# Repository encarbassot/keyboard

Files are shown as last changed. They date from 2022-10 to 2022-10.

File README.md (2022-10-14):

# Arduino Keyboard

- [Keyboard customization](keyboards/README.md)
- [How Keyboard hardware basic](playground/inputMatrix/README.md)
- [How Keyboard hardware DECO-MUX](playground/deco-mux/README.md)
- [Keyboard code examples](playground/README.md)

# Keyboards I've build

## Keyboard 48
more about [here](keyboard48/README.md)
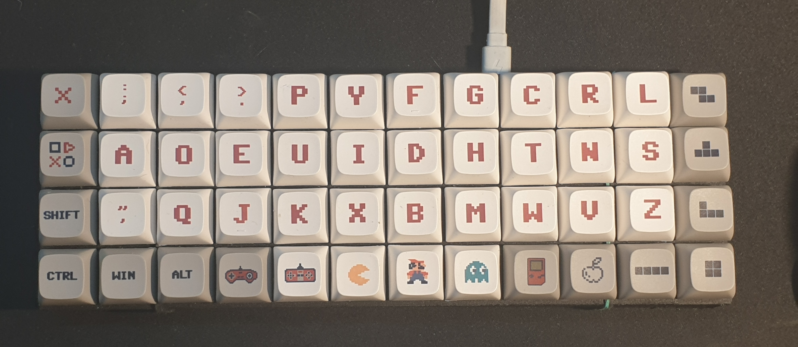
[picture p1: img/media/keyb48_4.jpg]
Keyboard 48


## Keyboard 64
more about [here](keyboard64/README.md)
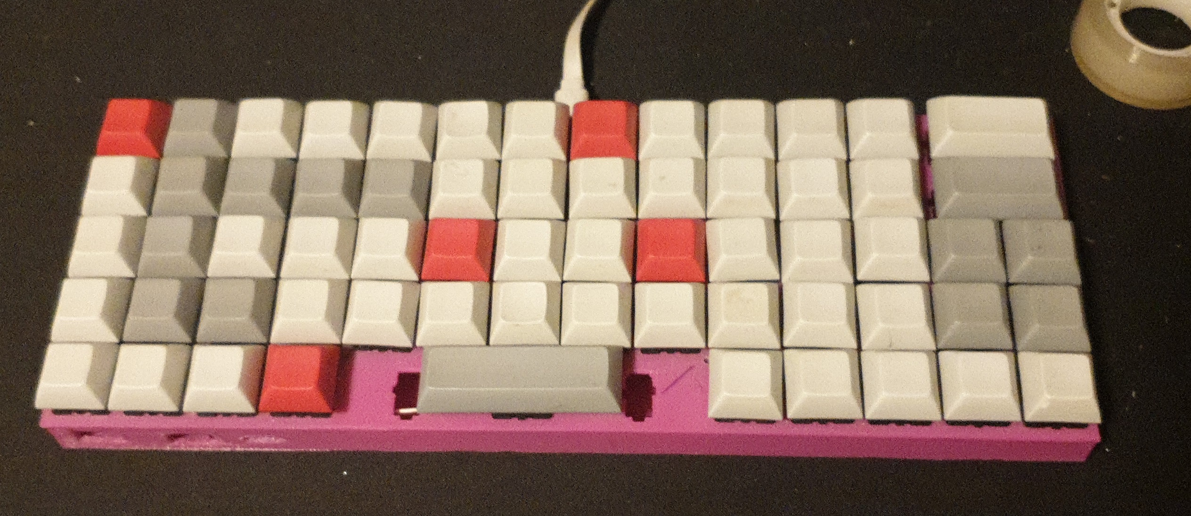
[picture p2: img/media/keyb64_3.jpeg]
Keyboard 64


All the documentation has been written by its own keyboard

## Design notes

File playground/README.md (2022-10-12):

# Playground
here are some codes that may help to understand de functionality of the keyboard
this wants to be a none over complicated way to understand the deep code of keyboard

## Learn more about DECODIFICATOR and MULTIPLEXOR
[DCO & MUX](deco-mux/README.md)

## Example codes
 - [deco-mux.ino](deco-mux/deco-mux/deco-mux.ino) explains how a **Multiplexer** and a **Decoder** works
 - [deco-mux-matrix.ino](deco-mux/deco-mux-matrix/deco-mux-matrix.ino) explains how to read a button matrix with a **Multiplexer** and a **Decoder**
 - [matrixInp.ino](inputMatrix/matrixInp/matrixInp.ino) Reads a button matrix without a multiplexer or decoder, raw input from row/column to Arduino input/output
 - [ascii.ino](ascii/ascii.ino) emulates a keyboard key press for each key that can exist and prints a table with the codes of ach key

 ## Interesting to include the next functionalities to the keyboard
 - [sd.ino](sd/sd.ino) reads a microSD and outputs the contents of a file
 - [oled.ino](oled/oled.ino) shows information via oled **SSD1306** (128×32) or (128x64) with [Adafruit library](https://github.com/adafruit/Adafruit_SSD1306)
 - [bluetooth.ino](bluetooth/bluetooth.ino) communication with phone to write from an app

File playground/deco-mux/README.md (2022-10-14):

# DECODER & MULTIPLEXOR

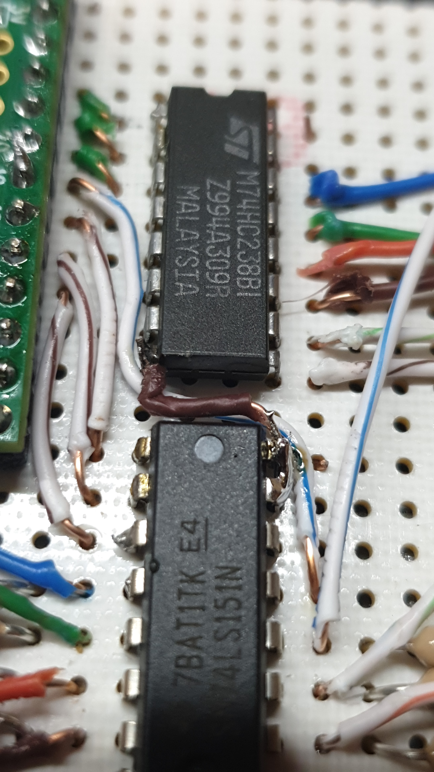
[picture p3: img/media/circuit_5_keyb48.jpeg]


### CODE EXAMPLES
  - [deco-mux.ino](deco-mux/deco-mux.ino) explains how a **Multiplexer** and a **Decoder** works
  - [deco-mux-matrix.ino](deco-mux-matrix/deco-mux-matrix.ino) explains how to read a button matrix with a **Multiplexer** and a **Decoder**
## Decoder
 - see on [wikipedia](https://wikipedia.org/wiki/Decodificador)  
 - [74HC238 datasheet](../../documentation/datasheet-DECO-M74HC238_STMicroelectronics.pdf)  

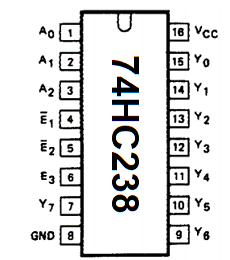
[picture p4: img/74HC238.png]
74HC238 pinout

 - **(A0,A1,A2)**-> microcontroller selector
 - **(Y0,Y1...Y6,Y7)**-> Decoder outputs
 - **(!E1,!E2,E3)** -> bring the option to connect 4 of them to create an **ULTRA-DECODER**
    - **!E1** and **!E2** set to ground (for normal operation)
    - **E3** set to 5V (for normal operation)
 - **VCC & GND** -> 🙃

A decoder has **n** inputs and **2<sup>n</sup>** outputs  
And what it does it's to trigger only the output that matches the input binary combination

for the **74HC238** that I'm using on the project, the output table is the next:

| A | B | C || Y0 | Y1 | Y2 | Y3 | Y4 | Y5 | Y6 | Y7 |
|---|---|---|-|----|----|----|----|----|----|----|----|
🔴|🔴|🔴| |🟢|🔴|🔴|🔴|🔴|🔴|🔴|🔴|
🔴|🔴|🟢| |🔴|🟢|🔴|🔴|🔴|🔴|🔴|🔴|
🔴|🟢|🔴| |🔴|🔴|🟢|🔴|🔴|🔴|🔴|🔴|
🔴|🟢|🟢| |🔴|🔴|🔴|🟢|🔴|🔴|🔴|🔴|
🟢|🔴|🔴| |🔴|🔴|🔴|🔴|🟢|🔴|🔴|🔴|
🟢|🔴|🟢| |🔴|🔴|🔴|🔴|🔴|🟢|🔴|🔴|
🟢|🟢|🔴| |🔴|🔴|🔴|🔴|🔴|🔴|🟢|🔴|
🟢|🟢|🟢| |🔴|🔴|🔴|🔴|🔴|🔴|🔴|🟢|

see it on action  
decpder gif

## Multiplexor
 A multiplexor its basically an input selector
 it has **n** channel selectors, **2<sup>n</sup>** inputs and 1 output  
 with the microcontroller, you can select any input by setting the channel selectors **HIGH** or **LOW**  
 then it will set its output to the value of the selected input

 - see on [wikipedia](wikipedia.org/wiki/Multiplexor)
 - [74LS151 datasheet](../../documentation/datasheet-MUX-74LS151.pdf)

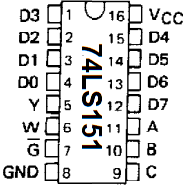
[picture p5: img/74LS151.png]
74LS151 pinout

 - **(A,B,C)**-> microcontroller channel selector
 - **(D0,D1..D6,D7)** -> Multipexor inputs
 - **(Y,W)** 
    - **Y** -> output
    - **W** -> negated output
 - **G** -> set to ground for formal operation

 | C|B|A|| Y | W |
|---|---|-|--|----|-|
🔴|🔴|🔴| |D0|!D0|
🔴|🔴|🟢| |D1|!D1|
🔴|🟢|🔴| |D2|!D2|
🔴|🟢|🟢| |D3|!D3|
🟢|🔴|🔴| |D4|!D4|
🟢|🔴|🟢| |D5|!D5|
🟢|🟢|🔴| |D6|!D6|
🟢|🟢|🟢| |D7|!D7|

## COMBINATION DECO & MUX
read first how [input matrix](../inputMatrix/README.md) works

## Functionality
Thanks to the chips 
 - 3 to 8 LINE DECODER [74HC238](../../documentation/datasheet-DECO-M74HC238_STMicroelectronics.pdf)
 - 8 to 3 LINE MULTIPLEXOR [74LS151](../../documentation/datasheet-MUX-74LS151.pdf)

 we can read up to 64 inputs with only 6+1 pins of the microcontroller

## Arduino pro micro
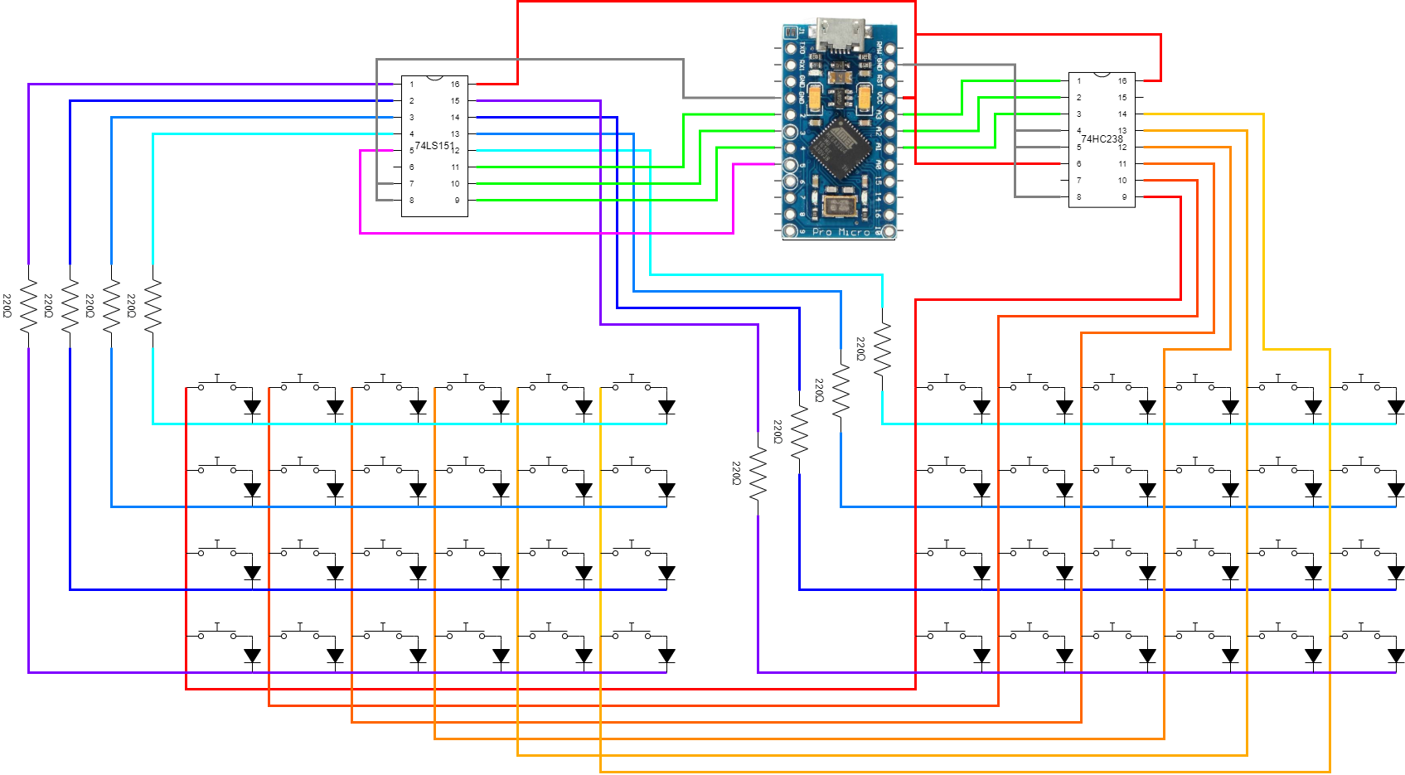
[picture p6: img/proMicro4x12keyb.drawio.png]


## TEENSY LC
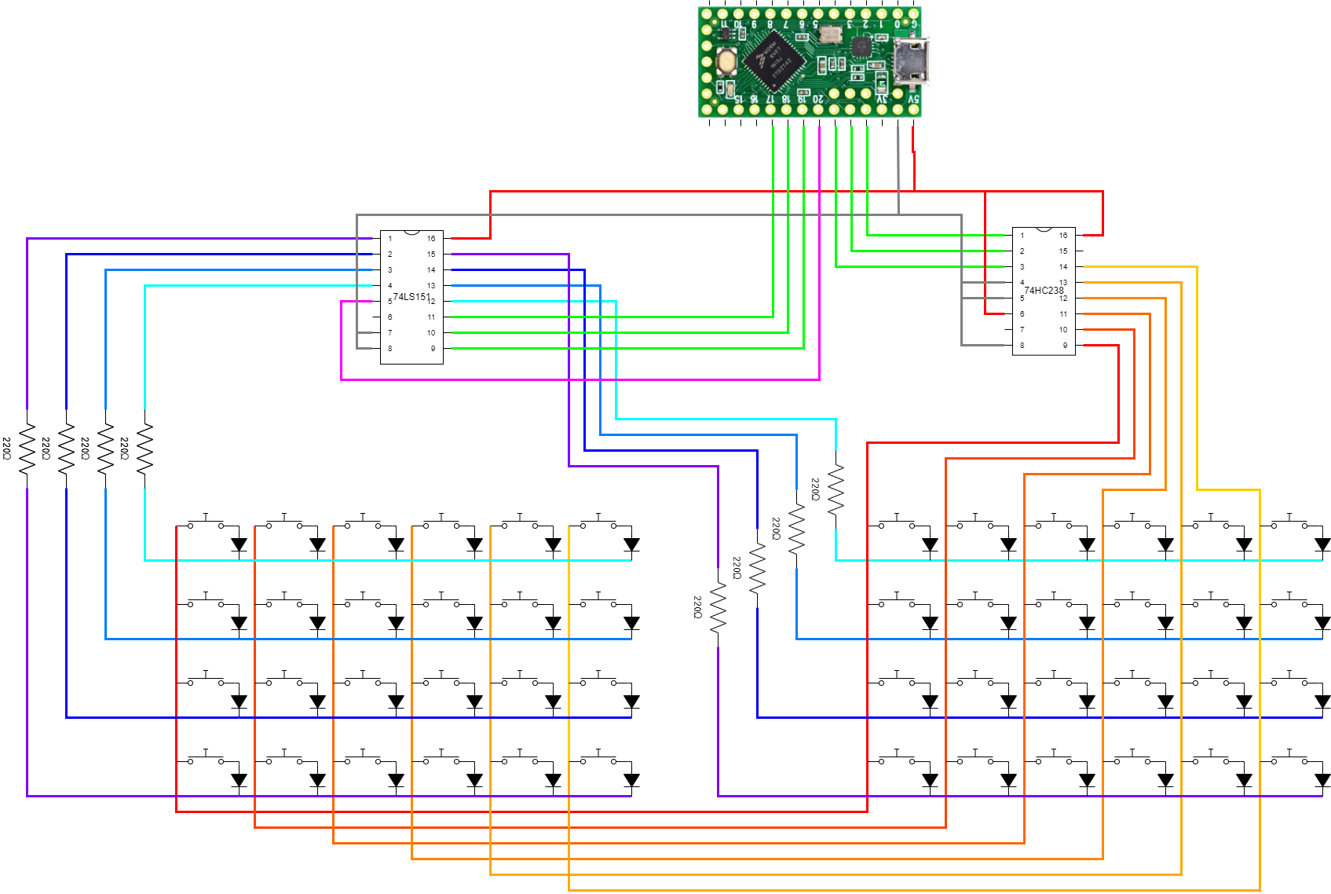
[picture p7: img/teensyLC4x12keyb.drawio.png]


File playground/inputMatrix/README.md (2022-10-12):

# INPUT MATRIX
When making a keyboard with a microcontroller the first question its,  
how am I supposed to read 64+ inputs with a board that has less than 20 gpio  

the answer to that its **INPUT MATRIX**

for the cost of **N+M** gpio you will read **N*M** inputs

|N+M|N*M|ratio inputs/GPIO|
|-|-|-|
|1+1 = **2** |1*1 = **1** | **0.5**  STUPID
|2+2 = **4** |2*2 = **4** | **1** USELESS
|3+3 = **6** |3*3 = **9** | **1.5**  BAD
|4+4 = **8** |4*4 = **16**| **2** NOT BAD
|5+5 = **10**|5*5 = **25**| **2.5**  BETTER
|4+6 = **10**|4*6 = **24**| **2.4**  WORSE
|3+7 = **10**|3*7 = **21**| **2.1**  WORSER

as you see, it grows exponencialy the ratio  
but as the difference of **N** and **M** gets bigger, the ratio also goes down
so we want to keep M and N as close as we can

## HOW IT WORKS
the DECODER sets each column, one at a time, and if a button is pressed the row will activate
and then the multiplexer will scan each row. If it detects the row activated, it will know row and column,
then it could decode which key it is

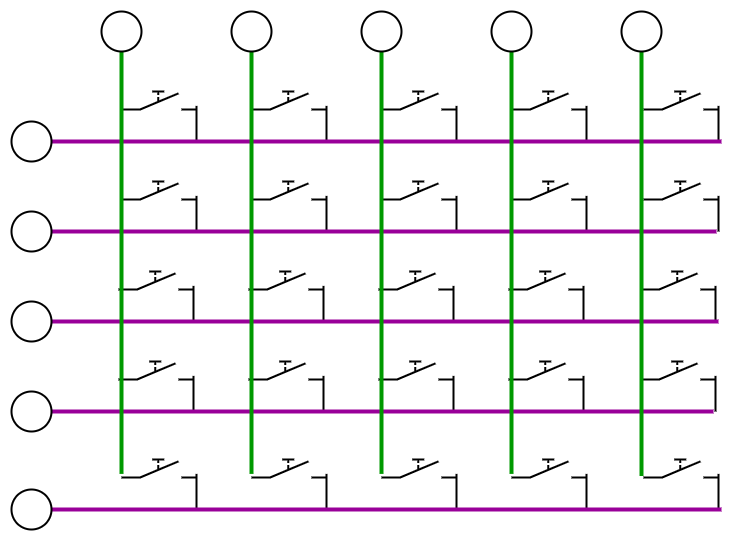
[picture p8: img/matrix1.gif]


## MULTIPLE PRESS
following the same process is able to detect multiple key presses at the same time

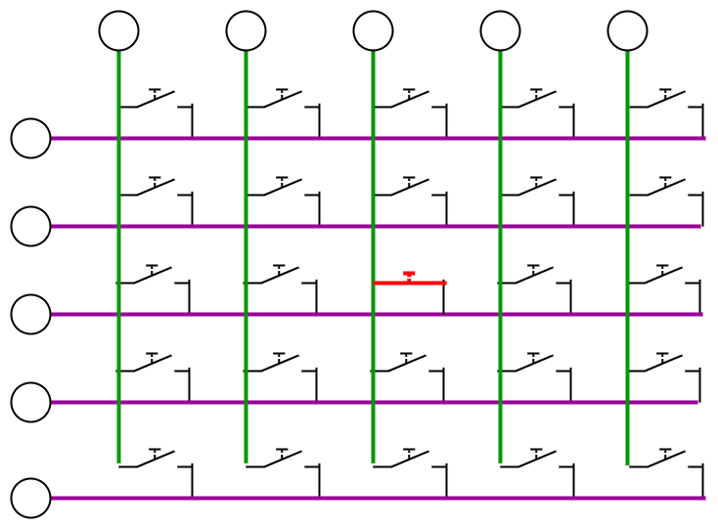
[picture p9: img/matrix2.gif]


## MULTIPLE PRESS GHOSTING
BUT if we press the buttons in a certain way, there will appear ghost key presses
the electricity will loop for the pressed buttons and activate rows that shouldn't be activated,

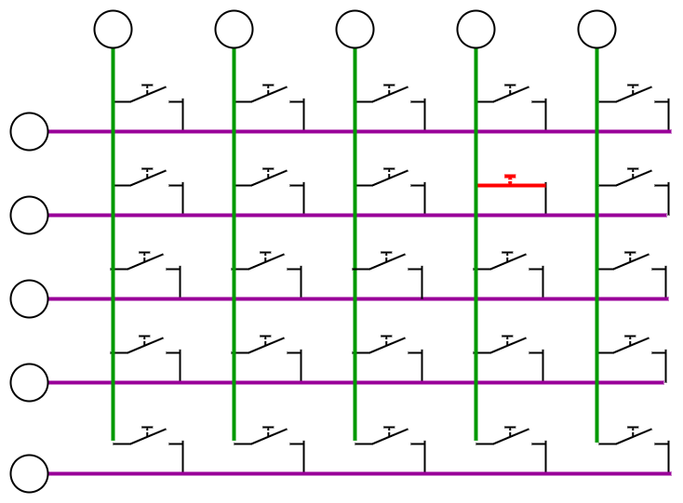
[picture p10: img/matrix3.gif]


## GHOSTIN SOLUTION
to resolve the ghosting solution, we will put diodes after each button, that way the electricity will exti any button but it will not enter to any button, preventing it from circulating wherever it wants

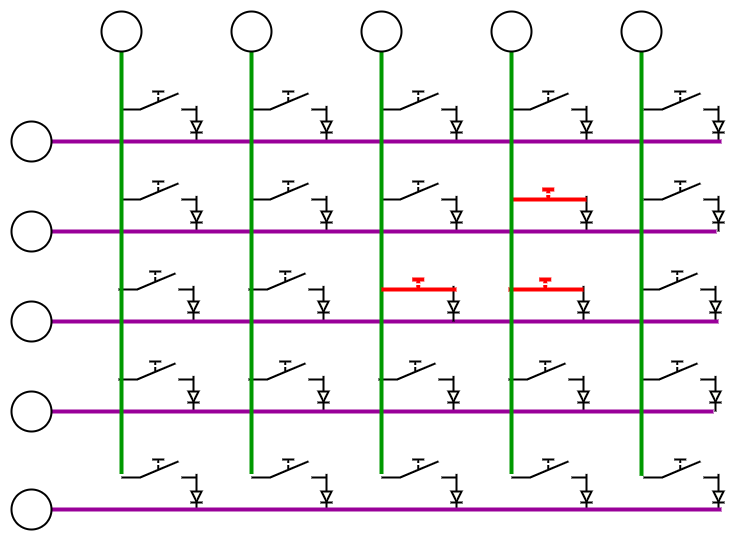
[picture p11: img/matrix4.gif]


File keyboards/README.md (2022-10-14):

# KEYBOARD PARAMETERS

Keyboards are a very deep world, there are infinite combinations to make a keyboard, as you can customize everything

Here i will explain some of the more usually customizations but take in mind that EVERYTHING is possible

you can add encoders, screens, joysticks, lazers, eye-tracking, voice-recognition, neuralink... whatever you can imagine

## KEYBOARD DISTRIBUTION
The keyboard distribution its the arrangement of the keys on the keyboard, the more usual its QWERTY since it got fame in the 1880's with the introduction of the typewriters in the offices.

**Qwerty** was made for typewriters to not get jammed, actually, some people think that was designed specially to slow you down, to give the typewriter time to retract. It was designed in 1868, and the first personal computers where released in the mid 70's, so there couldn't be a specific product.

100 years later, in the 1936  **DVORAK** was invented, to focus all the mainly used keys in the middle row, to minimize the finger travel distance. And then in the 2006 **COLEMAK** was invented with the same idea

There are lots of keyboard distributions now, even you can create your own if you want, for example dvorak has some for left handed, or right handed, one specially for programmers etc.

As you can see, both **Dvorak** and **Colemak**, they center the focus in the middle row, while **Qwerty** its a bit more chaotic.

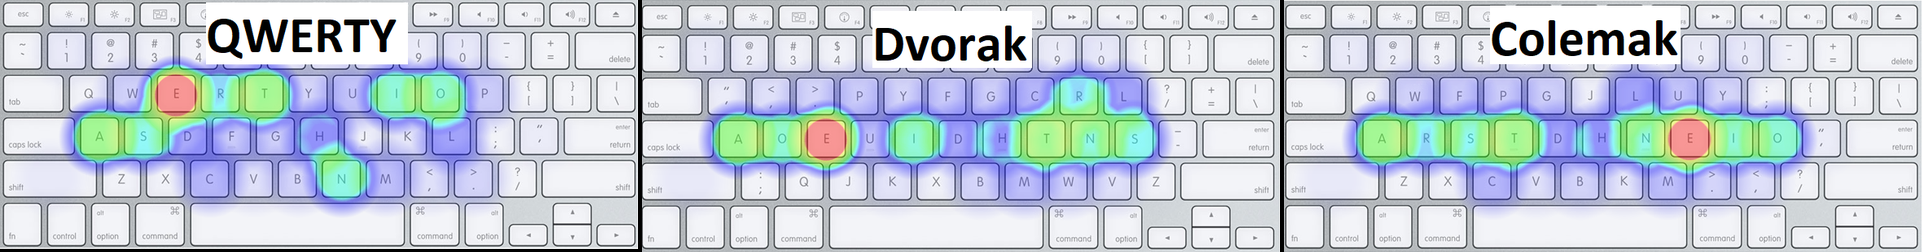
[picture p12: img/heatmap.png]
heatmap


## ORTHOLINEAR vs. STAGGERED
Also a design key of **Qwerty** was staggered keys, because the typewriters couldn't algin the keys for the mechanical arms bellow it.

Most of the people has get use to it, for the left hand its not an uncomfortable position, but its not symmetric, the right hand also has the keys tilted to the left.

Then appeared the **Ortholinear** keyboards that offer a straight grid for the keys but if you see, not all the fingers have the same length, for that reason the ortholinear has made an evolution to **Ortholinear ergonomic** that they usually are split keyboards. due to the small size ortholinears tend to became, you will end typing with your hands so close and uncomfortable angle. 

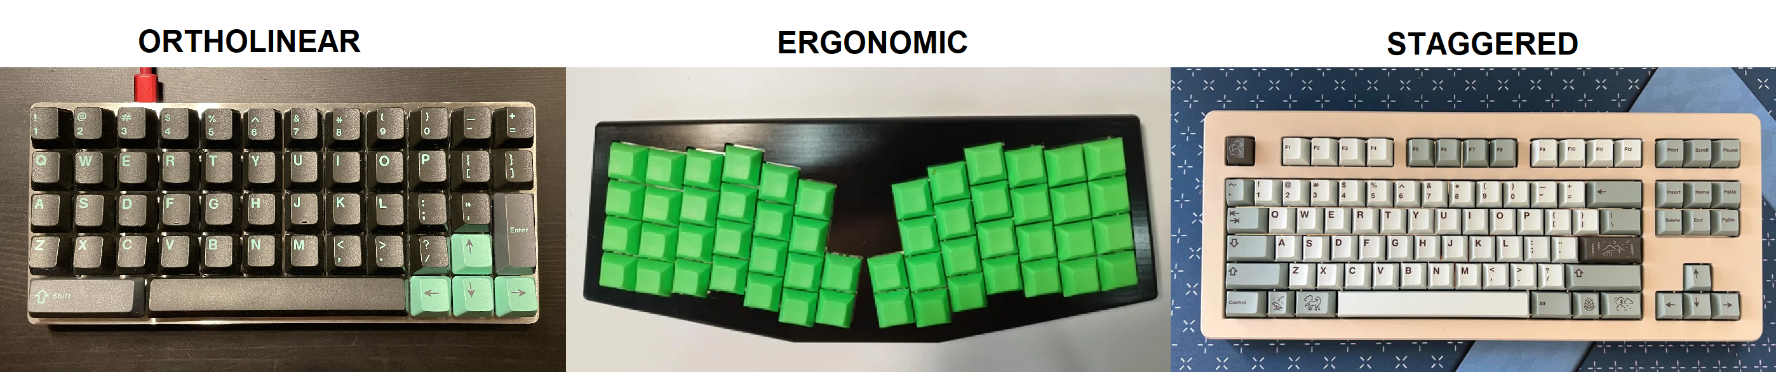
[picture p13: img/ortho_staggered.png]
comparation


## SLPIT KEYBOARD
They are an ergonomic solution to the problem that generates writing left and right keys so close while your arms are naturally separated. They can be just separated zones in one single device, or two devices that connect to each other.

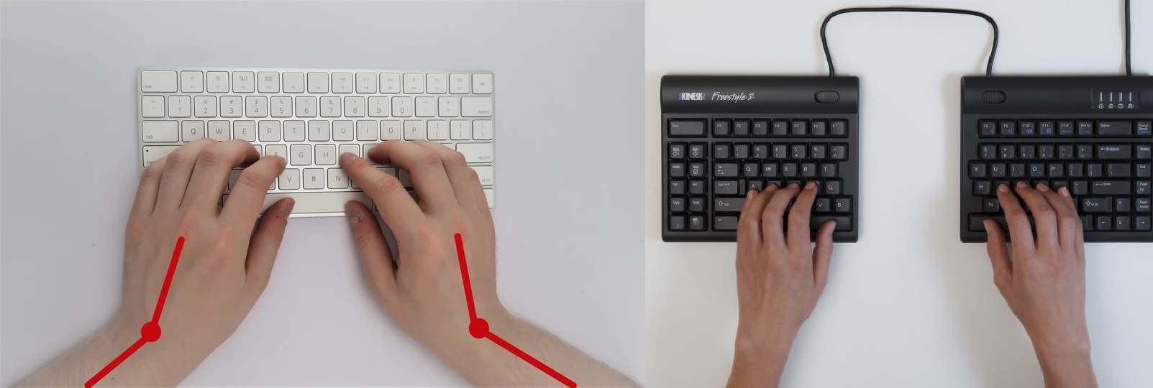
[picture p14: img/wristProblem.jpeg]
wrist


## KEYBOARD 100% 75% 65% 60% 40%
The theory its clear, as bigger the keyboard, more distance your hands will have to travel to reach every key, but what happen to all removed keys?
The keys are not removed, they are simply hidden by a layer. Like a phone keyboard that you press a key to access the numbers and symbols, here is the same, you usually have 1 or 2 FN keys to access the hidden layers.

**What does the percentage mean?**
A 100% keyboard or **Full-sized**, usually they have between 104 and 108 keys, so a 100% keyboard its a 100 ish keyboard, so 75% means 75 ish keys and so one...
- **100%** or FULL-SIZE: 
    - the regular keyboard, comfortable but bulky. for number entry its more useful and fast to have a numpad.
- **96%** or 1800 compact: 
    - this format its lost, its super rare to find one. Here you will lose the middle keys (Supr, Home, End, AvPag, RePag, ImpPant...)
- **87%** or Ten Key Less (TKL): 
    - Reducing the numpad you will get more space for the mouse, also you have the number row on the top, so the numpad its redundant.
- **75%**:
    - As 87% you will lose the numpad, but this tim the middle column will get squished to the main block and you may lose a few keys
- **65%**:
    - Its a 75% keyboard without F1...F12 keys basically
- **60%**:
    - Here you will lose the arrows and the remaining keys of the middle column, to access them you will need to use layers
- **40%**:
    - This is getting small, now you will lose the number row, now gaming tasks they may get compromised.
- **30%**:
    - This is as small as you can go, the Latin alphabet usually has 26 letters, so you will get 4 more keys to change between layers.

Of course there are a lot of keyboards and everyone its different and there may be 37% or 72% or strange numbers, there are infinite combinations.

# Keyboards I've build

## Keyboard 48
more about [here](keyboard48/README.md)
Keyboard 48

## Keyboard 64
more about [here](keyboard64/README.md)
Keyboard 64

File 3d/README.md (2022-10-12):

# 3D FILES

## 48keyboard
4x12 ortolineal keyboard  
all files [here](keyboard48/)
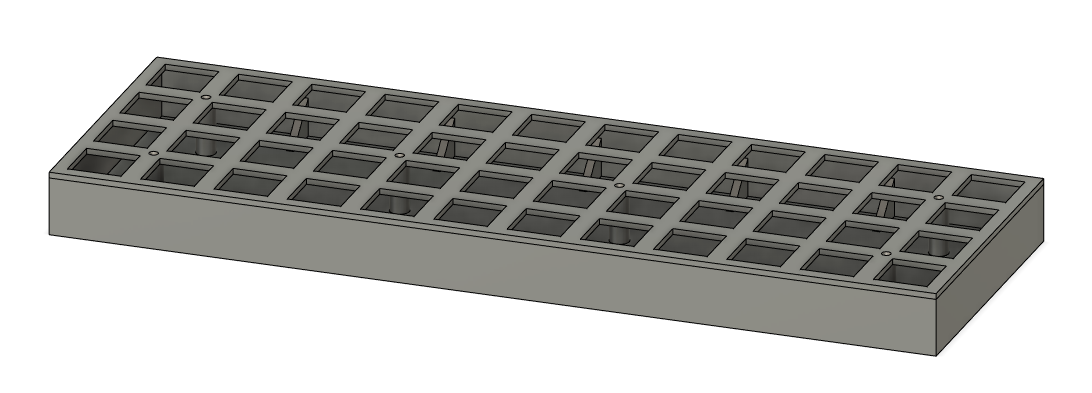
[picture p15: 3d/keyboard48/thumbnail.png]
48keyboard


## 64 keyboard
5x14 with a 5u space 2u return and 2u backspace  
all files [here](keyboard64/)
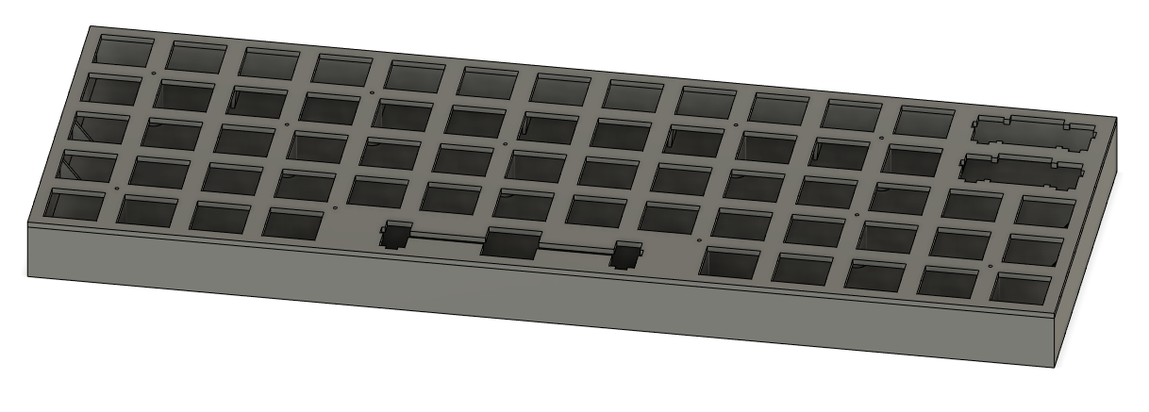
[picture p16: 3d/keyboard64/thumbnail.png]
48keyboard


## Macropad
4x4 macropad
all files [here](macropad4x4/)
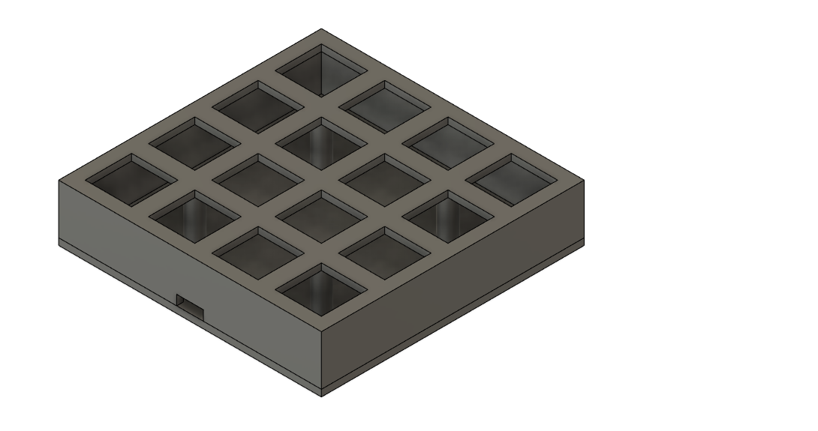
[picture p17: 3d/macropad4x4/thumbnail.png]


## Numpad
intended to use with a 128×64 SSD1306 oled  
all files [here](numpad/)
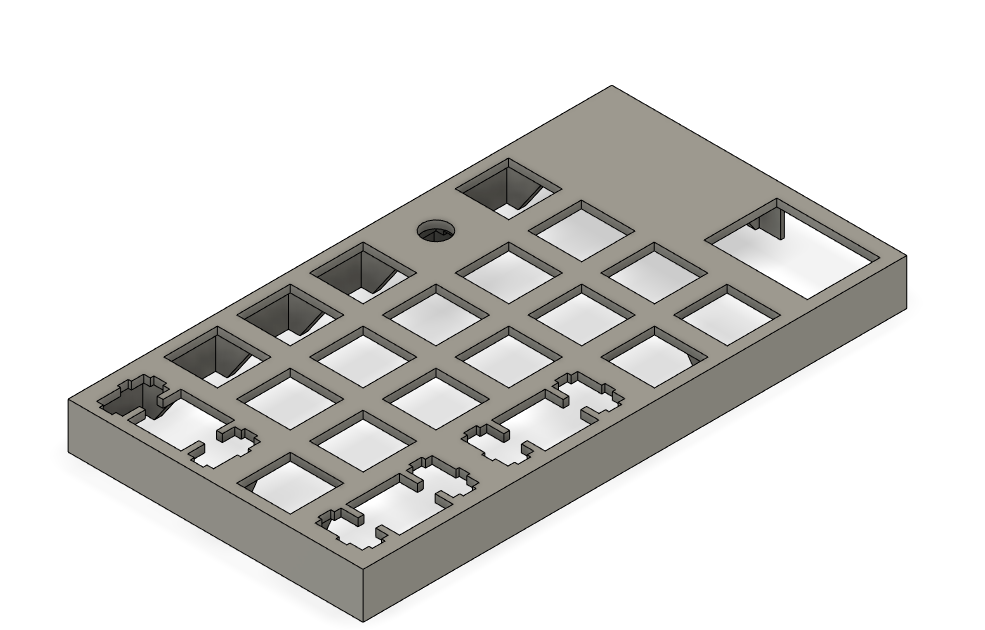
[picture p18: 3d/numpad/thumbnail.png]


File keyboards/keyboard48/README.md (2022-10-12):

# Keyboard 48
this is the **keyboard48** is the successor of [keyboard64](../keyboard64/README.md)  
and in this keyboard i implemented [DECO&MUX](../../playground/deco-mux/)
Keyboard 48

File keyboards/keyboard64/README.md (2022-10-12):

# Keyboard 64

Keyboard 64

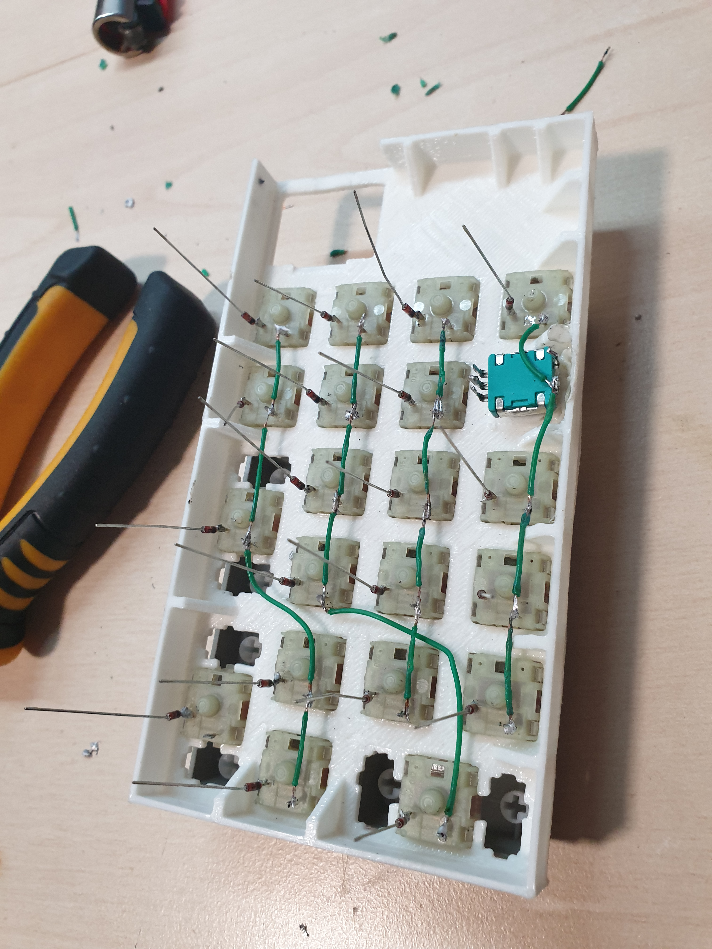
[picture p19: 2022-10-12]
img/media/numpad_1.jpg

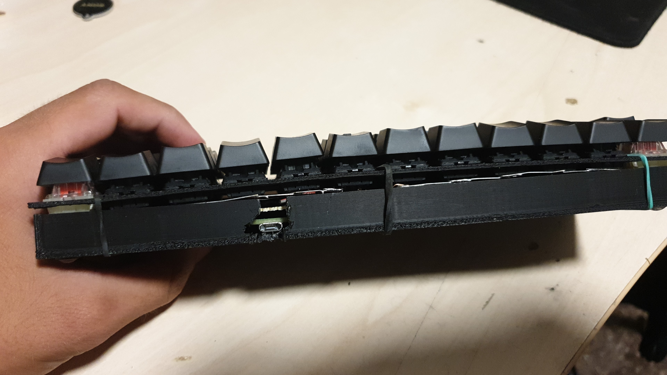
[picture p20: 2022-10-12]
img/media/keyb48_7.jpeg

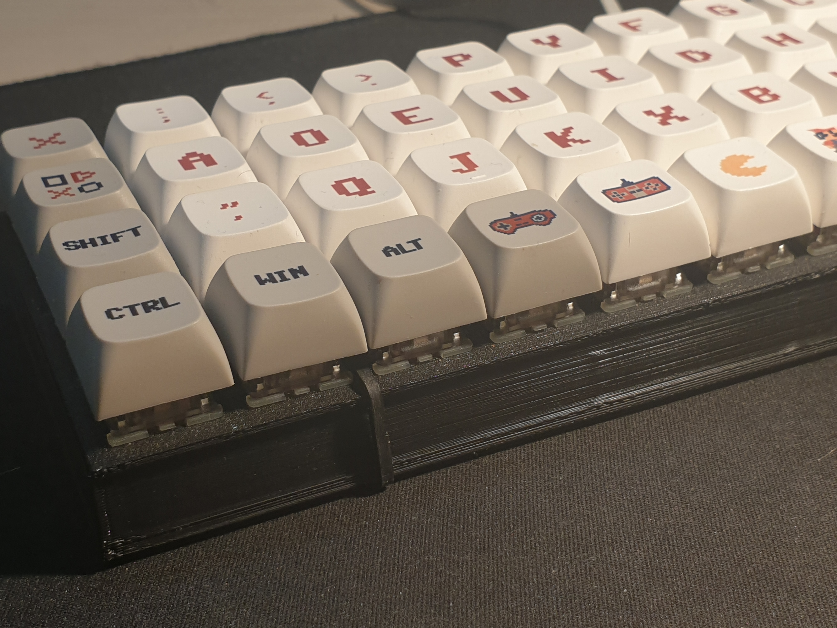
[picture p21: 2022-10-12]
img/media/keyb48_3.jpg

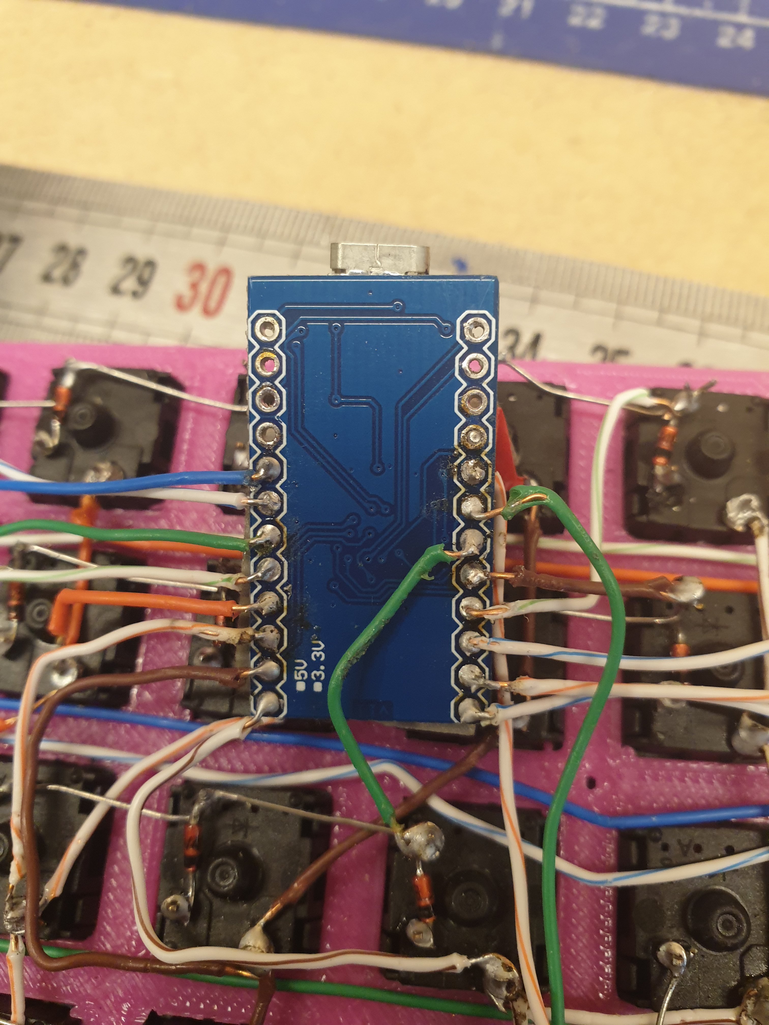
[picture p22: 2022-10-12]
img/media/keyb64_1.jpg

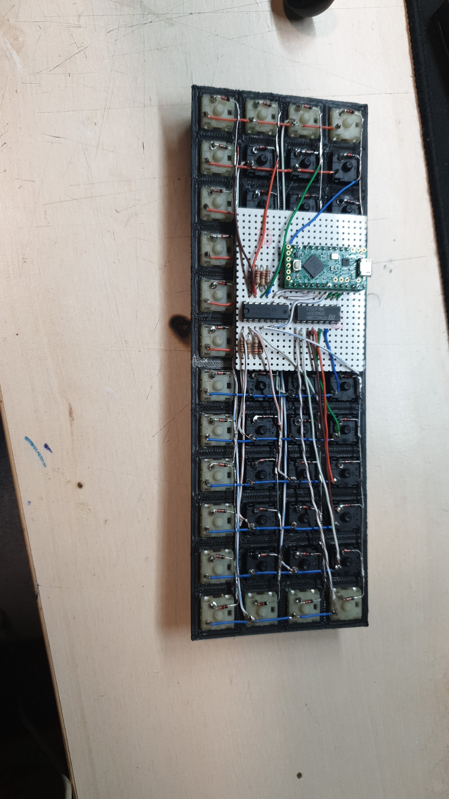
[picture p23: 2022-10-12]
img/media/keyb48_6.jpeg

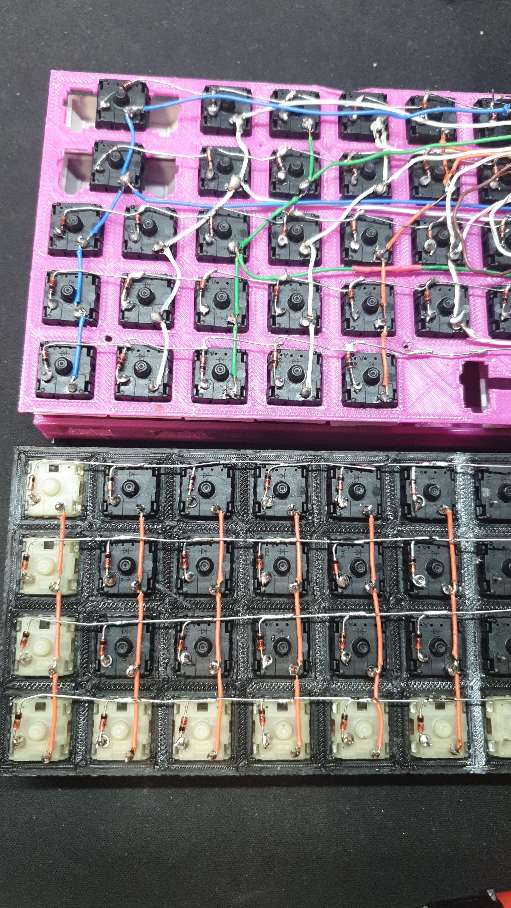
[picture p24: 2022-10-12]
img/media/circuit_4_keyb64_keyb48.jpeg

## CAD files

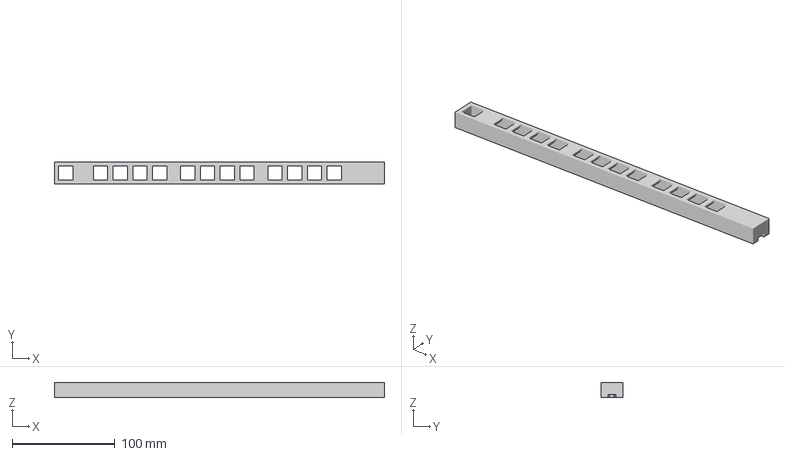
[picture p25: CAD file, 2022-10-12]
3d/Fkeyboard/pool.3mf
321.4 x 21.9 x 15.0 mm

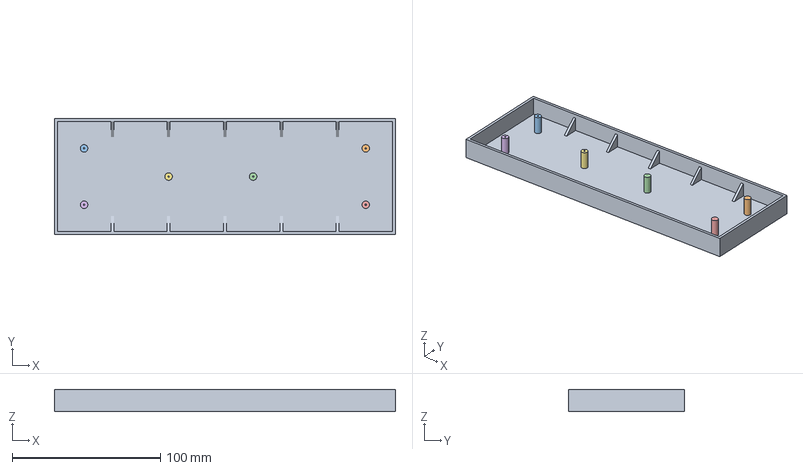
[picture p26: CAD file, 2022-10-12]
3d/keyboard48/pool.3mf
230.0 x 78.0 x 15.0 mm

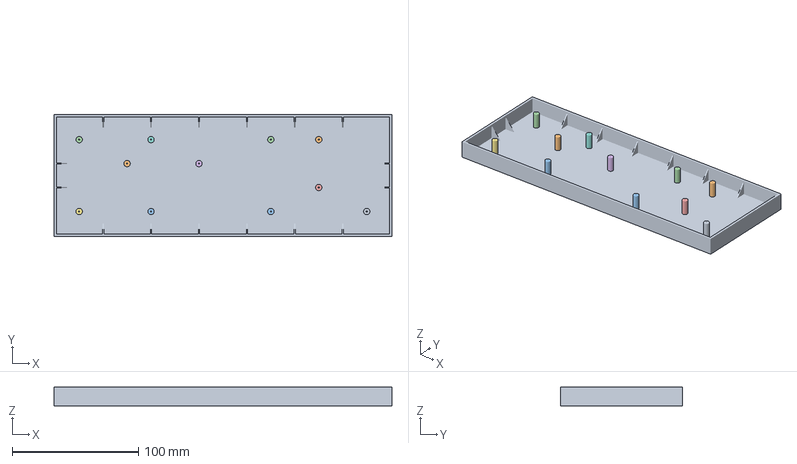
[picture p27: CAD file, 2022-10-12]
3d/keyboard64/pool.3mf
268.0 x 97.0 x 15.0 mm

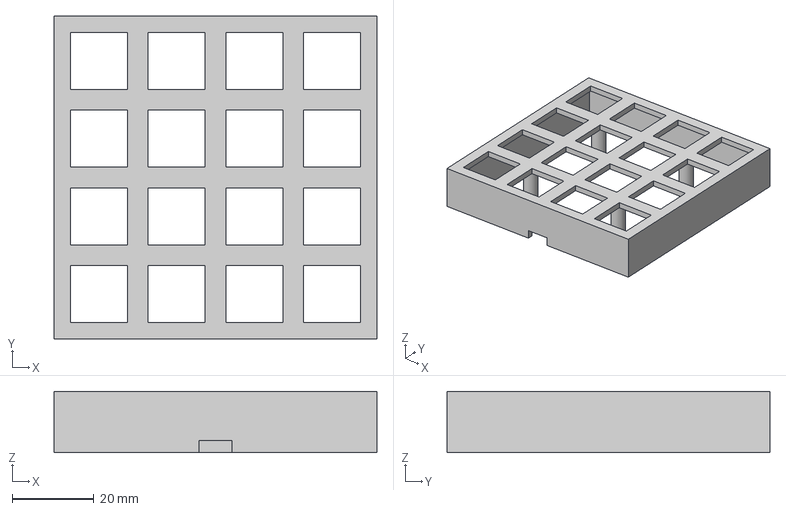
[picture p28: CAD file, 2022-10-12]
3d/macropad4x4/pool.3mf
78.9 x 78.9 x 15.0 mm

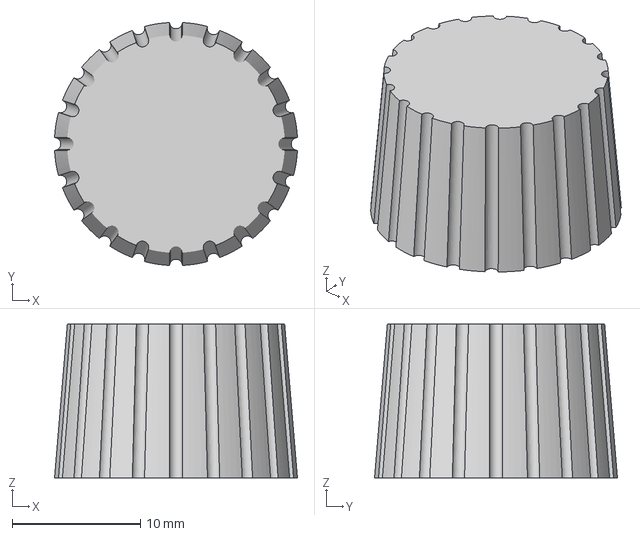
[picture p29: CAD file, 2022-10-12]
3d/miscelaneous/keyboardEncoderKnob.3mf
19.0 x 19.0 x 12.0 mm

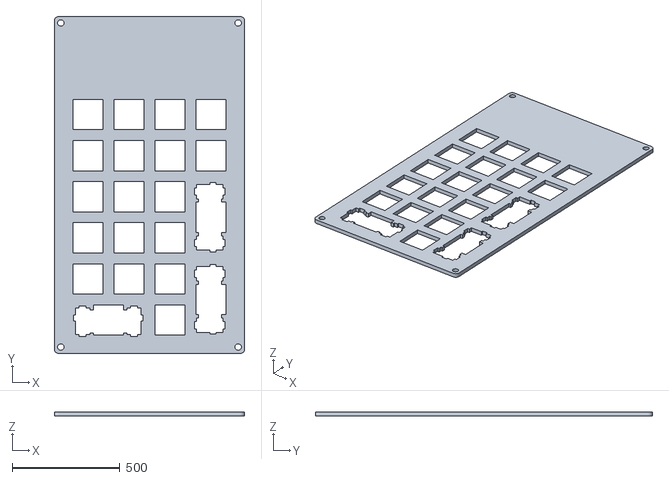
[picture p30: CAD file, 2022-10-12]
3d/numpad/Top v1.stl
882.0 x 1562.5 x 20.0

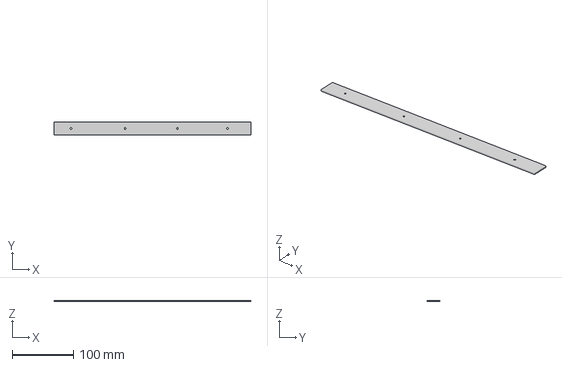
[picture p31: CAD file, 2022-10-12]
3d/Fkeyboard/plate.3mf
321.4 x 21.9 x 2.00 mm

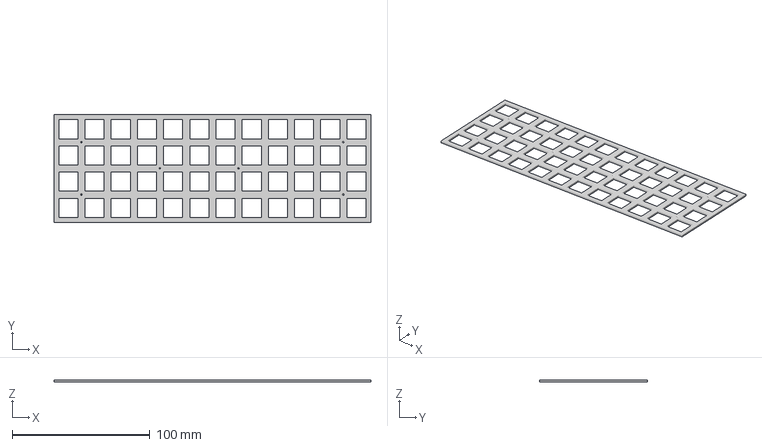
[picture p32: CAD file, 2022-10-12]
3d/keyboard48/plate.3mf
230.0 x 78.0 x 1.52 mm

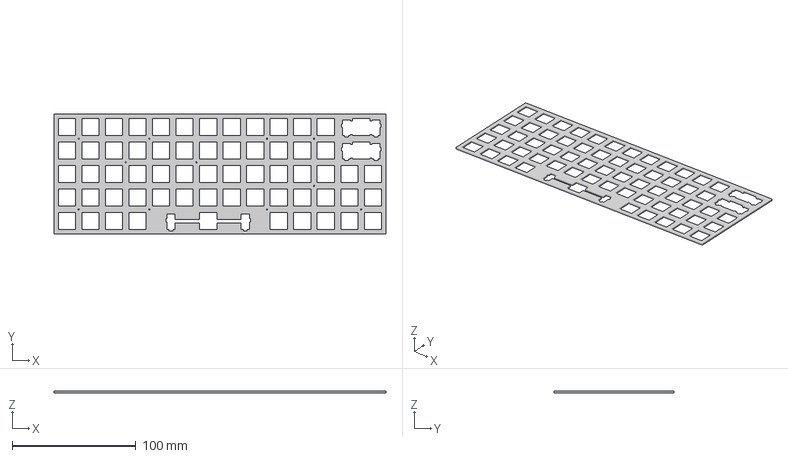
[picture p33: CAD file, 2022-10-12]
3d/keyboard64/plate.3mf
268.0 x 97.0 x 1.52 mm

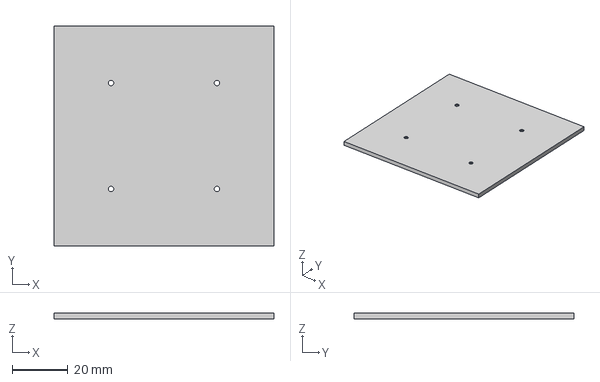
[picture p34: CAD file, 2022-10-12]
3d/macropad4x4/plate.3mf
78.9 x 78.9 x 2.00 mm

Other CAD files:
3d/Fkeyboard/Fkeyboard.f3d
3d/keyboard48/keyboard48.f3d
3d/keyboard64/keyboard64.f3d
3d/keyboard64/plate.stl
3d/keyboard64/pool.stl
3d/macropad4x4/macropad4x4.f3d
3d/miscelaneous/keyboardEncoderKnob.f3d

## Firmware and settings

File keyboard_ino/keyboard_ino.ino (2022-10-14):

#include "Keyb.h"
//#include "CONFIG.h"

Keyb k;

void setup(){
  k.setup();
}

void loop(){
  k.loop();
}




/******TO*DO*******
what if not defined BOARD_DECODER & BOARD_MULTIPLEXER

read bloqMayus and blocqNum status to nevel let it be enabled

key recorders class

after release Hmodifier wait few millis to release other keys, then act

scanForKeys() if 2 modifiers pressed goes crazy
 */

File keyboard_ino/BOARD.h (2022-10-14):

#include "Arduino.h"
#ifndef BOARD_H
#define BOARD_H

#define TEENSY

#define VIRTUAL_COLUMNS 8
#define VIRTUAL_ROWS 8

#define BOARD_DECODER //DECODER 74HC238
#ifdef BOARD_DECODER
  const unsigned char pins_deco[] = {23,22,21};//{6,7,8};
  #define PINS_DECO_LEN 3
#endif


#define BOARD_MULTIPLEXER//MULTIPLEXOR 74LS151
#ifdef BOARD_MULTIPLEXER
  const unsigned char pins_mux[] =  {17,18,19};//{3,4,5};
  #define PINS_MUX_LEN 3
  #define PIN_MUX_INP 20//2aaaaaaa
  
#endif

#define ADJACENCY_MATRIX
//may take a few milliseconds on the boot.
#ifdef ADJACENCY_MATRIX

#if !defined(BOARD_MULTIPLEXER) || !defined(BOARD_DECODER)
  const unsigned char mat_outs[] = {A3,A2,A1,A0,15,14,16,10};   //OUTPUT
  const unsigned char mat_inps[] = {2 ,3 ,4 ,5 ,6 ,7 ,8 ,9 };   //INPUT
#endif

#define FISICAL_COLUMNS 16
#define FISICAL_ROWS 4


  const unsigned char adjacencyMatrix[VIRTUAL_ROWS][VIRTUAL_COLUMNS][2]={//enter a virtual position & return fisical position
    {{0,15},{1,15},{2,15},{3,15},{3,14},{2,14},{1,14},{0,14}},
    {{0, 7},{1, 7},{2, 7},{3, 7},{3,13},{2,13},{1,13},{0,13}},
    {{0, 6},{1, 6},{2, 6},{3, 6},{3,12},{2,12},{1,12},{0,12}},
    {{0, 5},{1, 5},{2, 5},{3, 5},{3,11},{2,11},{1,11},{0,11}},
    {{0, 4},{1, 4},{2, 4},{3, 4},{3,10},{2,10},{1,10},{0,10}},
    {{0, 3},{1, 3},{2, 3},{3, 3},{3, 9},{2, 9},{1, 9},{0, 9}},
    {{0, 2},{1, 2},{2, 2},{3, 2},{3, 8},{2, 8},{1, 8},{0, 8}},
    {{0, 1},{1, 1},{2, 1},{3, 1},{3, 0},{2, 0},{1, 0},{0, 0}}
  };//*/  

#endif //ADJACENCY MATRIX

#endif //BOARD_H

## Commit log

2022-10-12 initial stage
2022-10-12 3D models and more examples
    [64key v1.step, 64key.f3d, Top v1.f3d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]
2022-10-12 in 3D Renamed 64keyboard to keyboard64 and added keyboard48
    [64key v1.step, keyboard48.f3d, keyboard64.f3d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]
2022-10-12 3D thumbnails
    [Top v1.f3d]
2022-10-12 adding media images
    [Fkeyboard.f3d, keyboardEncoderKnob.3mf, keyboardEncoderKnob.f3d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]
